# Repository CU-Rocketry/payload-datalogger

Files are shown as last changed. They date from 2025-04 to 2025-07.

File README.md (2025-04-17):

# payload-datalogger

Wirelessly configurable thermocouple data logging PCB implementing four MCP96RL00T on-board thermocouple to I2C converter ICs, an ESP32-C3 MCU, and flash storage.

## Screenshots

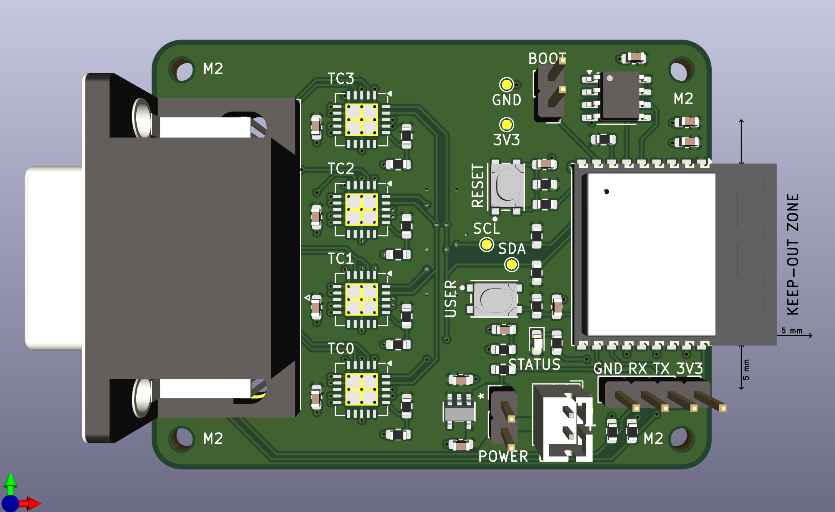
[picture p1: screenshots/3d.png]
3d

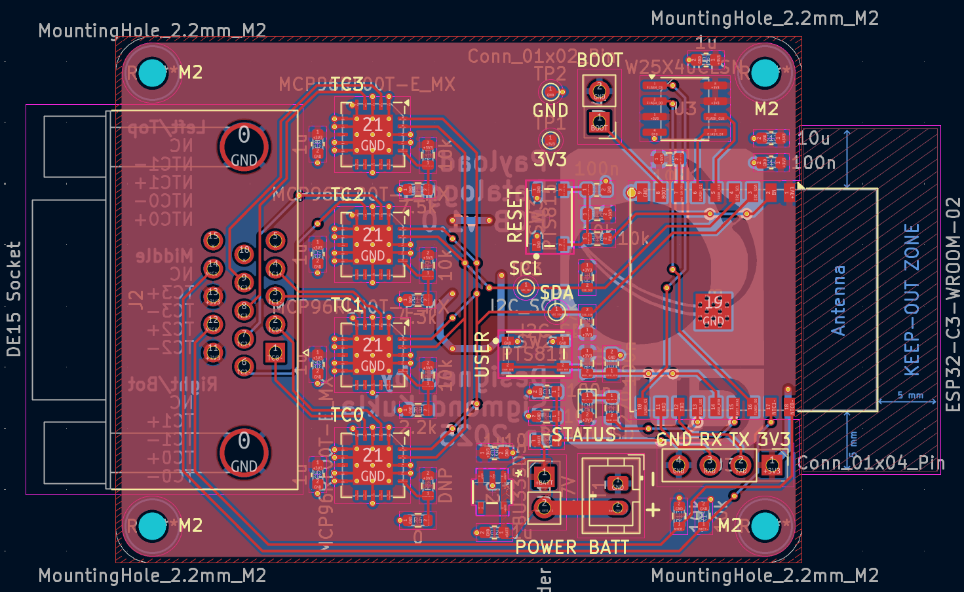
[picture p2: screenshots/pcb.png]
pcb

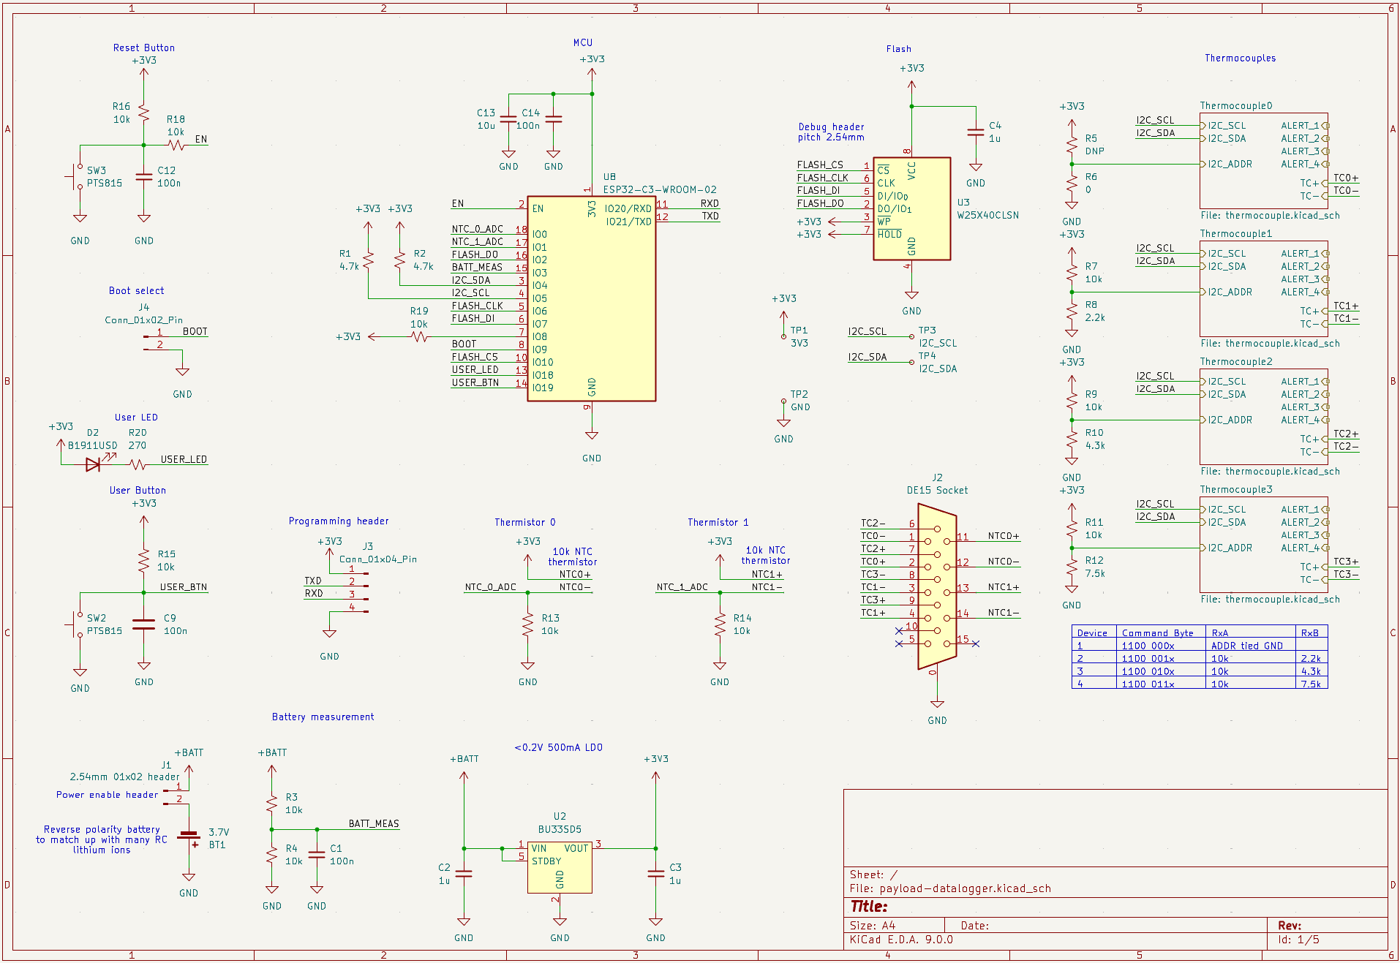
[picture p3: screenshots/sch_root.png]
schematic root

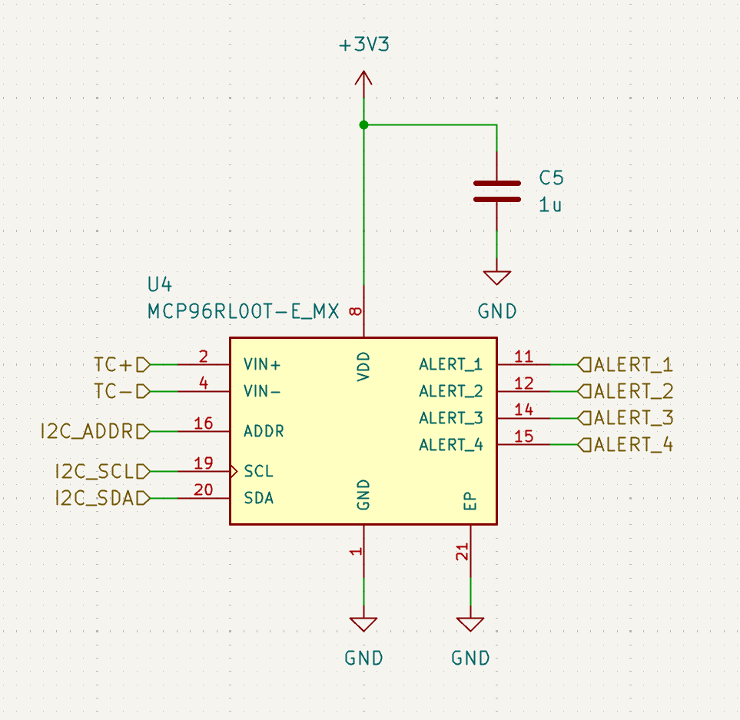
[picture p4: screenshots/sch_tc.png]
schematic thermocouple


## BOM

See [this spreadsheet].(https://docs.google.com/spreadsheets/d/12Mr7GmqM8tnob1ocJkmMWgOL1p1aouqN9iYZXRkocOg/edit?usp=sharing)

**BOM cost:** $65 (on DigiKey, for two boards with attrition)
Does not include cables.

Additionally, batteries should be purchased elsewhere such as the suggested Amazon links to remain economical.

## Firmware

Firmware source code is located in the `src/payload-datalogger` directory.
Source code, for ease of modification by all team members, relies on the Arduino hardware abstraction layer (HAL).
The PlatformIO IDE and toolchain is required to build and debug the firmware, meaning that the minimum prerequisites for payload datalogger firmware development are:
- [Visual Studio Code](https://code.visualstudio.com/download)
- [PlatformIO IDE extension](https://marketplace.visualstudio.com/items?itemName=platformio.platformio-ide)

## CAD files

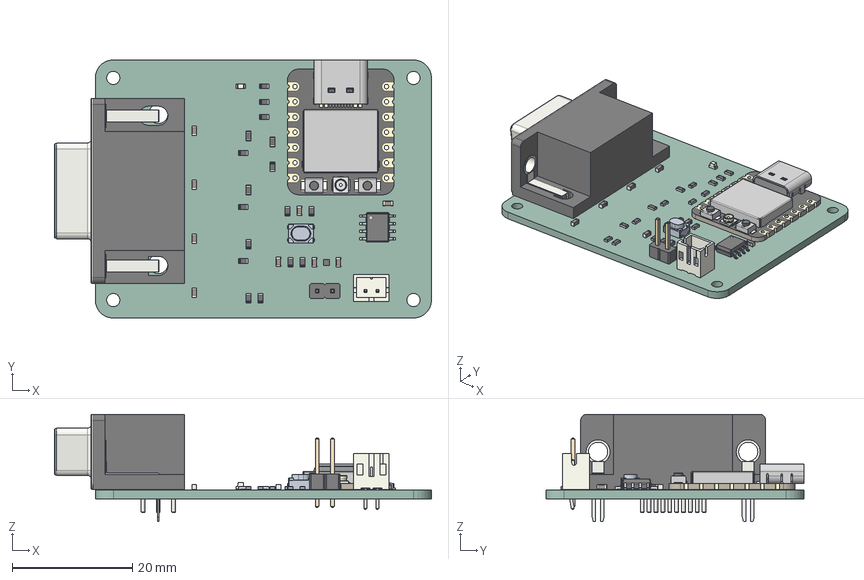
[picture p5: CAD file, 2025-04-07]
pcb/payload-datalogger.step
62.8 x 43.0 x 17.9 mm
C_0603_1608Metric x 9
JST_PH_B2B-PH-K_1x02_P2.00mm_Vertical
R_0603_1608Metric x 17
BOSS-EXTRUDE14_8_
BOSS-EXTRUDE7_4_
BOSS-EXTRUDE7_3_
BOSS-EXTRUDE14_4_
BOSS-EXTRUDE14_2_
BOSS-EXTRUDE14_11_
BOSS-EXTRUDE7_7_
BOSS-EXTRUDE14_9_
BOSS-EXTRUDE14_3_
BOSS-EXTRUDE14_7_
MIRROR2
BOSS-EXTRUDE14_5_
BOSS-EXTRUDE14_12_
BOSS-EXTRUDE7_8_
BOSS-EXTRUDE7_1_
BOSS-EXTRUDE14_10_
BOSS-EXTRUDE7_9_
BOSS-EXTRUDE14_6_
BOSS-EXTRUDE14_1_
BOSS-EXTRUDE7_6_
BOSS-EXTRUDE7_2_
CUT-EXTRUDE5
BOSS-EXTRUDE7_5_
U.FL Connector v1
Button (1) x 2
Shield
OnSemi_XDFN4-1EP_1.0x1.0mm_EP0.52x0.52mm
PinHeader_1x02_P2.54mm_Vertical
LED_0603_1608Metric
PTS815SJM250SMTRLFS_PART1
PTS815SJM250SMTRLFS_PART2
PTS815SJM250SMTRLFS_PART3
SOIC-8_3.9x4.9mm_P1.27mm
DSUB-15-HD_Socket_Horizontal_P2.29x2.54mm_EdgePinOffset8.35mm_Housed_ MountingHolesOffset10.89mm
payload-datalogger_PCB

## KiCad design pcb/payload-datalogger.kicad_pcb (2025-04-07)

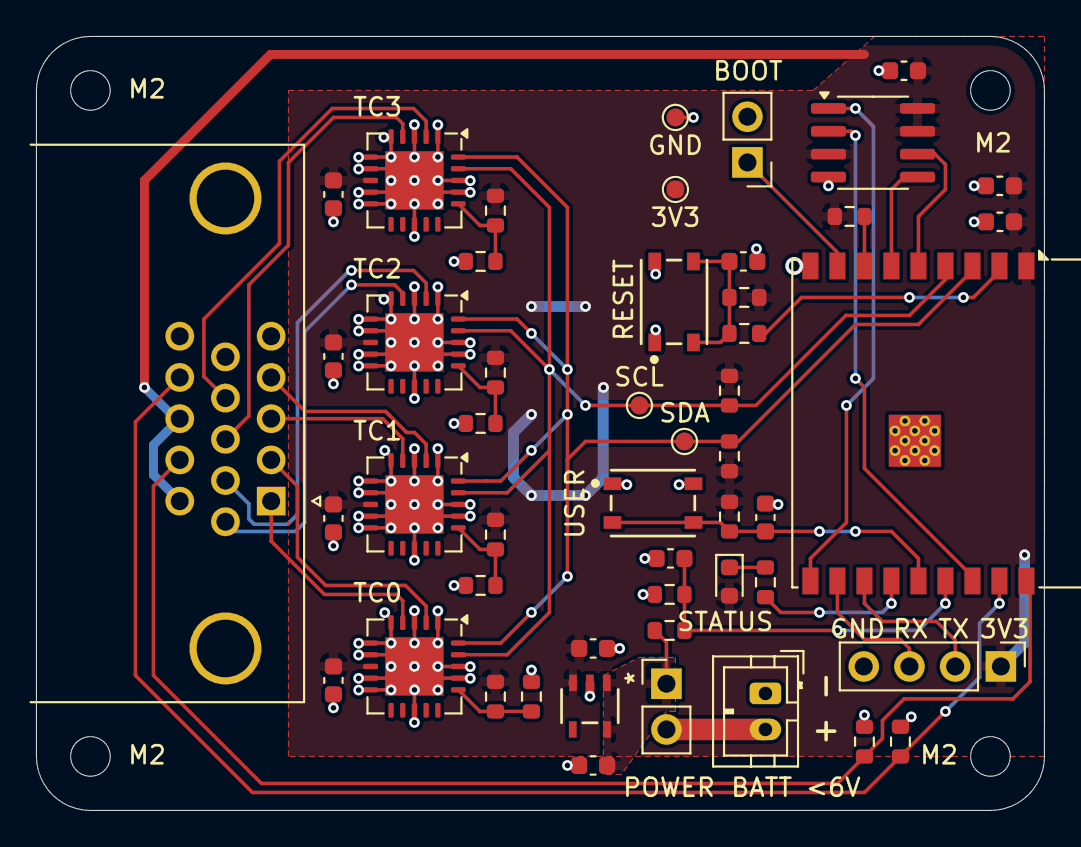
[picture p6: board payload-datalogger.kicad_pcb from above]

Board: 2 copper layers, 56.0 x 43.0 mm, 50 parts (0 on the bottom side), 34 nets.

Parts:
BT1: 3.7V; JST_PH_B2B-PH-K_1x02_P2.00mm_Vertical
C1, C9, C12, C14: 100n; C_0603_1608Metric
C2, C3, C4, C5, C6, C7, C8: 1u; C_0603_1608Metric
C13: 10u; C_0603_1608Metric
D2: B1911USD; LED_0603_1608Metric
J1: 2.54mm 01x02 header; PinHeader_1x02_P2.54mm_Vertical
J2: DE15 Socket; DSUB-15-HD_Socket_Horizontal_P2.29x2.54mm_EdgePinOffset8.35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
J3: Conn_01x04_Pin; PinHeader_1x04_P2.54mm_Vertical
J4: Conn_01x02_Pin; PinHeader_1x02_P2.54mm_Vertical
R1, R2: 4.7k; R_0603_1608Metric
R3, R4, R7, R9, R11, R13, R14, R15, R16, R18, R19: 10k; R_0603_1608Metric
R5: DNP; R_0603_1608Metric
R6: 0; R_0603_1608Metric
R8: 2.2k; R_0603_1608Metric
R10: 4.3k; R_0603_1608Metric
R12: 7.5k; R_0603_1608Metric
R20: 270; R_0603_1608Metric
SW2, SW3: PTS815; SW_Push_PTS815_SJM_250_SMTR_LFS
TP1: 3V3; TestPoint_Pad_D1.0mm
TP2: GND; TestPoint_Pad_D1.0mm
TP3: I2C_SCL; TestPoint_Pad_D1.0mm
TP4: I2C_SDA; TestPoint_Pad_D1.0mm
U2: BU33SD5; SSOP5_ROM
U3: W25X40CLSN; SOIC-8_3.9x4.9mm_P1.27mm
U4, U5, U6, U7: MCP96RL00T-E_MX; TQFN-20-1EP_5x5mm_P0.65mm_EP3.25x3.25mm
U8: ESP32-C3-WROOM-02

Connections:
+3V3: C3.1, C4.1, C5.1, C6.1, C7.1, C8.1, C13.1, C14.1, D2.2 (A), J2.11, J2.13, J3.1, R1.1, R2.1, R5.2, R7.2, R9.2, R11.2, R15.1, R16.2, R19.1, TP1.1, U2.3 (VOUT), U3.3 (~WP), U3.7 (~HOLD), U3.8 (VCC), U4.8 (VDD), U5.8 (VDD), U6.8 (VDD), U7.8 (VDD), U8.1 (3V3)
+BATT: C2.1, J1.1, R3.1, U2.1 (VIN), U2.5 (STDBY)
/BATT_MEAS: C1.1, R3.2, R4.1, U8.15 (IO3)
/BOOT: J4.1, U8.8 (IO9)
/EN: R18.2, U8.2 (EN)
/FLASH_CLK: U3.6 (CLK), U8.5 (IO6)
/FLASH_CS: U3.1 (~CS), U8.10 (IO10)
/FLASH_DI: U3.5 (DI/IO_{0}), U8.6 (IO7)
/FLASH_DO: U3.2 (DO/IO_{1}), U8.16 (IO2)
/I2C_SCL: R1.2, TP3.1, U4.19 (SCL), U5.19 (SCL), U6.19 (SCL), U7.19 (SCL), U8.4 (IO5)
/I2C_SDA: R2.2, TP4.1, U4.20 (SDA), U5.20 (SDA), U6.20 (SDA), U7.20 (SDA), U8.3 (IO4)
/NTC0-: J2.12, R13.1, U8.18 (IO0)
/NTC1-: J2.14, R14.1, U8.17 (IO1)
/RXD: J3.3, U8.11 (IO20/RXD)
/TC0+: J2.2, U4.2 (VIN+)
/TC0-: J2.1, U4.4 (VIN-)
/TC1+: J2.4, U5.2 (VIN+)
/TC1-: J2.3, U5.4 (VIN-)
/TC2+: J2.7, U6.2 (VIN+)
/TC2-: J2.6, U6.4 (VIN-)
/TC3+: J2.9, U7.2 (VIN+)
/TC3-: J2.8, U7.4 (VIN-)
/TXD: J3.2, U8.12 (IO21/TXD)
/Thermocouple0/I2C_ADDR: R5.1, R6.2, U4.16 (ADDR)
/Thermocouple1/I2C_ADDR: R7.1, R8.2, U5.16 (ADDR)
/Thermocouple2/I2C_ADDR: R9.1, R10.2, U6.16 (ADDR)
/Thermocouple3/I2C_ADDR: R11.1, R12.2, U7.16 (ADDR)
/USER_BTN: C9.1, R15.2, SW2.2, U8.14 (IO19)
/USER_LED: R20.2, U8.13 (IO18)
GND: BT1.1 (+), C1.2, C2.2, C3.2, C4.2, C5.2, C6.2, C7.2, C8.2, C9.2, C12.2, C13.2, C14.2, J2.0, J3.4, J4.2, R4.2, R6.1, R8.1, R10.1, R12.1, R13.2, R14.2, SW2.1, SW3.1, TP2.1, U2.2 (GND), U3.4 (GND), U4.1 (GND), U4.3 (GND), U4.5 (GND), U4.6 (GND), U4.7 (GND), U4.9 (GND), U4.10 (GND), U4.13 (GND), U4.17 (GND), U4.18 (GND), U4.21 (EP), U5.1 (GND), U5.3 (GND), U5.5 (GND), U5.6 (GND), U5.7 (GND), U5.9 (GND), U5.10 (GND), U5.13 (GND), U5.17 (GND), U5.18 (GND), U5.21 (EP), U6.1 (GND), U6.3 (GND), U6.5 (GND), U6.6 (GND), U6.7 (GND), U6.9 (GND), U6.10 (GND), U6.13 (GND), U6.17 (GND), U6.18 (GND), U6.21 (EP), U7.1 (GND), U7.3 (GND), U7.5 (GND), U7.6 (GND), U7.7 (GND), U7.9 (GND), U7.10 (GND), U7.13 (GND), U7.17 (GND), U7.18 (GND), U7.21 (EP), U8.9 (GND), U8.19 (GND)
unnamed: BT1.2 (-), J1.2
unnamed: C12.1, R16.1, R18.1, SW3.2
unnamed: D2.1 (K), R20.1
unnamed: R19.2, U8.7 (IO8)

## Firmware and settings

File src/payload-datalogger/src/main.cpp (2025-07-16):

#include <Arduino.h>
#include <WiFi.h>
#include <ESPAsyncWebServer.h>
#include <SPIFFS.h>
#include "peripherals.h"
#include "UserLED.h"
#include "UserButton.h"
#include <Thermistor.h>
#include <NTC_Thermistor.h>
#include "MCP9600.h"
#include <SPIMemory.h>
#include <cstdint>
#include <cstring>
#include <array>
#include <Preferences.h> // to store settings
#include <nvs_flash.h>

// ESP32 will create an AP with these credentials
const char *ssid = "CUR_Payload_Datalogger";
const char *password = "12345678";

IPAddress local_ip(192, 168, 1, 1); // static IP for ESP32
IPAddress gateway(192, 168, 1, 1);  // gateway is ESP32 itself
IPAddress subnet(255, 255, 255, 0); // subnet mask

AsyncWebServer server(80);

String renderLedToggleDiv();
String renderUserButtonDiv();
String renderRecordingToggleDiv();
String renderTimestepInputDiv();
String renderDownloadDiv();
String renderFlashDiv();
String renderTemperatureTable();
String renderIndex();

// Thermistors
#define NTC_REF_R 10000
#define NTC_NOMINAL_R 10000
#define NTC_NOMINAL_T 25
#define NTC_B 3435

NTC_Thermistor_ESP32 ntc0(NTC_0_PIN, NTC_REF_R, NTC_NOMINAL_R, NTC_NOMINAL_T, NTC_B, 3300, 4095);
NTC_Thermistor_ESP32 ntc1(NTC_1_PIN, NTC_REF_R, NTC_NOMINAL_R, NTC_NOMINAL_T, NTC_B, 3300, 4095);

#define TC0_ADDRESS 0x60
#define TC1_ADDRESS 0x61
#define TC2_ADDRESS 0x62
#define TC3_ADDRESS 0x63

TwoWire wire = TwoWire(0);

MCP9600 tc0(TC0_ADDRESS, &wire);
MCP9600 tc1(TC1_ADDRESS, &wire);
MCP9600 tc2(TC2_ADDRESS, &wire);
MCP9600 tc3(TC3_ADDRESS, &wire);

UserLED status_led(USER_LED_PIN);
UserButton user_btn(USER_BUTTON_PIN);

SPIFlash flash(FLASH_CS, &SPI);
uint32_t flash_capacity = 0;
uint32_t flash_pointer = 0; // should be aligned with page size
#define SECTOR_SIZE 4096 // 4kB sector size

bool led_state = false;
uint32_t last_led_time = 0;                // [ms] since boot
#define STATUS_LED_IDLE_DURATION 100       // [ms]
#define STATUS_LED_IDLE_DELAY 500          // [ms]
#define STATUS_LED_RECORDING_DURATION 1000 // [ms]
#define STATUS_LED_RECORDING_DELAY 1000    // [ms]

enum class LoggingState
{
    IDLE,
    RECORDING
};
LoggingState logging_state = LoggingState::IDLE;
uint32_t logging_interval = 1000; // [ms] between logging events, default to 1s
uint32_t last_logging_time = 0;   // [ms] since boot
uint32_t current_time = 0;        // [ms] since boot, fine for ~50 days
uint32_t start_time = 0;         // [ms] since boot, used to calculate timestamps
uint32_t timestamp = 0;         // [ms] since recording began
uint32_t iteration = 0;           // number of data points logged

#pragma pack(push, 1) // ensure no padding between struct members
struct DataPoint
{
    uint32_t iteration;
    uint32_t timestamp; // [ms] since boot
    float ntc0_temp;    // [C], assuming 32 bit float
    float ntc1_temp;    // [C]
    float tc0_temp;     // [C]
    float tc1_temp;     // [C]
    float tc2_temp;     // [C]
    float tc3_temp;     // [C]
};
#pragma pack(pop) // restore default packing
static_assert(sizeof(DataPoint) == 32, "DataPoint must be exactly 32 bytes");
#define POINTS_PER_PAGE (256 / sizeof(DataPoint)) // 8 data points per page
using Page = std::array<DataPoint, POINTS_PER_PAGE>;
using Buffer = std::array<std::uint8_t, sizeof(DataPoint) * POINTS_PER_PAGE>;
static_assert(Buffer{}.size() == 256, "Serialized page must be 256 bytes");

/*
We have 524,288 bytes of flash available (512kB).
This means that with each data point being 32 bytes, we may store 16,384 data points in total.
At a rate of 1 point per second, this gives us a total logging time of 4.5 hours.
If we log every 10 seconds, we can log for 45 hours.
*/

Page current_page; // Buffer for the current page of data points

Preferences preferences;

void flash_init();
void ap_init();
void webserver_init();
void thermocouples_init();
bool flushPageToFlash(const Page &page);
void flushPartialPage();
void loadMetadata();
void saveMetadata();
void dumpFlash();

void setup()
{
    Serial.begin(115200);
    // Serial.begin(921600);
    Serial.println("Serial started");


    // ONCE ONLY
    // Serial.println("Initializing NVS");
    // nvs_flash_erase();
    // nvs_flash_init();
    // preferences.begin("datalogger", false);
    // while(1);

    // thermocouples_init();
    flash_init();

    loadMetadata();

    dumpFlash(); // for debugging

    Serial.println("Flash dump complete");

    while (1){}

    status_led.init();
    user_btn.init();

    

    if (!SPIFFS.begin(true)) // for static file serving, true: format if mount fails
    {
        Serial.println("Error mounting SPIFFS");
        return;
    }
    Serial.println("SPIFFS mounted successfully");

    ap_init();
    webserver_init();

    Serial.println("Setup complete");
}

void loop()
{
    current_time = millis();
    timestamp = current_time - start_time;

    switch (logging_state)
    {
    case LoggingState::IDLE:
        // nothing needed here yet
        break;

    case LoggingState::RECORDING:
        // log data if timer elapsed
        if (current_time - last_logging_time >= logging_interval)
        { // if enough time has passed to log a new point

            // get all temperatures
            float ntc0_temp = ntc0.readCelsius();
            float ntc1_temp = ntc1.readCelsius();
            float tc0_temp = tc0.getHotJunctionTemp();
            float tc1_temp = tc1.getHotJunctionTemp();
            float tc2_temp = tc2.getHotJunctionTemp();
            float tc3_temp = tc3.getHotJunctionTemp();

            DataPoint data_point = {iteration, timestamp, ntc0_temp, ntc1_temp, tc0_temp, tc1_temp, tc2_temp, tc3_temp};

            current_page[iteration % POINTS_PER_PAGE] = data_point;

            last_logging_time = current_time; // reset timer
            iteration++;                      // increment iteration count

            if (iteration > 0 && iteration % POINTS_PER_PAGE == 0) // if we filled the page and are moving onto a new one
            {
                // write to flash
                if (flushPageToFlash(current_page))
                {
                    Serial.println("Successfully wrote page to flash");
                }
                else
                {
                    Serial.println("Failed to write page to flash.");
                }
            }
        }
        break;
    }

    // status LED blinking
    uint32_t led_delay;
    uint32_t led_duration;
    switch (logging_state)
    {
    case LoggingState::IDLE:
        led_delay = STATUS_LED_IDLE_DELAY;
        led_duration = STATUS_LED_IDLE_DURATION;
        break;

    case LoggingState::RECORDING:
        led_delay = STATUS_LED_RECORDING_DELAY;
        led_duration = STATUS_LED_RECORDING_DURATION;
        break;
    }
    if (led_state)
    {
        if (current_time - last_led_time >= led_duration)
        {
            status_led.set(false); // turn off LED
            led_state = false;
            last_led_time = current_time; // reset timer
        }
    }
    else
    {
        if (current_time - last_led_time >= led_delay)
        {
            status_led.set(true); // turn on LED
            led_state = true;
            last_led_time = current_time; // reset timer
        }
    }

    delay(10); // small delay to avoid busy loop
}

void flash_init()
{
    Serial.println("Flash init");
    SPI.begin(FLASH_CLK, FLASH_DO, FLASH_DI, FLASH_CS);

    flash.begin();
    // flash.setClock(1000000); // requires experimentation
    flash_capacity = flash.getCapacity();
    Serial.printf("Flash initialized. Capacity: %lu bytes\n", flash_capacity);
}

void ap_init()
{
    Serial.println("WiFi AP init");
    WiFi.softAP(ssid, password);
    WiFi.softAPConfig(local_ip, gateway, subnet);
    Serial.println("WiFi AP configured");
    Serial.print("SSID: ");
    Serial.println(ssid);
    Serial.print("Password: ");
    Serial.println(password);
    Serial.print("AP IP Address: ");
    Serial.println(WiFi.softAPIP());
}

void webserver_init()
{
    Serial.println("Web server init");

    server.serveStatic("/htmx.min.js", SPIFFS, "/htmx.min.js");
    server.serveStatic("/favicon.ico", SPIFFS, "/favicon.ico");
    server.serveStatic("/logo.png", SPIFFS, "/logo.png");

    server.on("/", HTTP_GET, [](AsyncWebServerRequest *request)
              { request->send(200, "text/html", renderIndex()); });

    server.on("/toggle_status_led", HTTP_POST, [](AsyncWebServerRequest *request)
              {
        led_state = !led_state;
        status_led.set(led_state);
        request->send(200, "text/html", renderLedToggleDiv()); });

    server.on("/user_button_state", HTTP_GET, [](AsyncWebServerRequest *request)
              { request->send(200, "text/html", renderUserButtonDiv()); });

    server.on("/toggle_recording", HTTP_POST, [](AsyncWebServerRequest *request)
              {
        if (logging_state == LoggingState::IDLE) {
            logging_state = LoggingState::RECORDING;
            Serial.println("Recording started.");
            last_logging_time = millis(); // Reset timer when starting
            start_time = millis(); // Reset start time for timestamp calculations
        } else if (logging_state == LoggingState::RECORDING) {
            logging_state = LoggingState::IDLE;
            flushPartialPage();
            Serial.println("Recording stopped.");
            // Optionally, write any remaining data in current_page if it's partially filled
            // This requires more complex logic to write a partial page or pad it. This could be a pain.
        }
        request->send(200, "text/html", renderRecordingToggleDiv()); });

    server.on("/set_rate", HTTP_POST, [](AsyncWebServerRequest *request)
              {
        if (request->hasParam("rate", true)) {
            int rate_val = request->getParam("rate", true)->value().toInt();
            if (rate_val > 0) {
                logging_interval = (uint32_t)rate_val;
                Serial.printf("Logging interval set to: %lu ms\n", logging_interval);
            } else {
                Serial.println("Invalid rate value received.");
            }
        }
        request->send(200, "text/html", renderTimestepInputDiv()); });

    server.on("/download_data", HTTP_GET, [](AsyncWebServerRequest *request)
              {
        Serial.println("Data download requested.");

        if (logging_state != LoggingState::IDLE) {
            request->send(400, "text/plain", "Stop logging before downloading.");
            return;
        }

        AsyncResponseStream *response = request->beginResponseStream("text/csv");
        response->addHeader("Content-Disposition", "attachment; filename=\"cur_payload_log.csv\"");
        response->print("Iteration,Timestamp,NTC0_Temp,NTC1_Temp,TC0_Temp,TC1_Temp,TC2_Temp,TC3_Temp\n");

        if (iteration == 0) {
            response->print("No data logged yet.\n");
            request->send(response);
            return;
        }
        
        Page data_page_buffer;
        uint32_t current_read_address = 0;
        uint32_t points_retrieved = 0;
        uint32_t total_points_to_read = iteration;

        Serial.printf("Preparing to download %lu data points. Flash pointer at %lu.\n", total_points_to_read, flash_pointer);

        while (current_read_address < flash_pointer && points_retrieved < total_points_to_read) {
            if (!flash.readAnything(current_read_address, data_page_buffer)) {
                Serial.printf("Flash read error at address %lu\n", current_read_address);
                break;
            }

            for (int i = 0; i < POINTS_PER_PAGE; ++i) {
                if (points_retrieved >= total_points_to_read) break;

                const DataPoint& dp = data_page_buffer[i];
                response->printf("%lu,%lu,%.3f,%.3f,%.3f,%.3f,%.3f,%.3f\n",
                                 dp.iteration, dp.timestamp, dp.ntc0_temp, dp.ntc1_temp,
                                 dp.tc0_temp, dp.tc1_temp, dp.tc2_temp, dp.tc3_temp);
                points_retrieved++;
            }
            current_read_address += sizeof(Page);
            
            delay(1); // yield in case of long downloads. maybe should yield longer even
        }
        
        Serial.printf("Sent %lu data points.\n", points_retrieved);
        request->send(response); });

    server.on("/flash_usage", HTTP_GET, [](AsyncWebServerRequest *request)
              { request->send(200, "text/html", renderFlashDiv()); });

    server.on("/refresh_table", HTTP_GET, [](AsyncWebServerRequest *request)
              { request->send(200, "text/html", renderTemperatureTable()); });

    server.on("/format_flash", HTTP_POST, [](AsyncWebServerRequest *request)
              {
        if (logging_state == LoggingState::RECORDING) {
            request->send(400, "text/plain", "Cannot format while recording.");
            return;
        }
        
        Serial.println("Formatting flash chip...");
        flash.eraseChip(); // Erase the flash
        
        // FIX: Reset local variables and persisted metadata in NVS
        flash_pointer = 0;
        iteration = 0;
        saveMetadata(); // Save the reset state
        
        Serial.println("Flash formatted successfully.");
        request->send(200, "text/html", renderFlashDiv()); });

    server.begin();
    Serial.println("Web server started");
}

void thermocouples_init()
{
    Serial.println("Thermocouples init");

    wire.begin(I2C_SDA, I2C_SCL, 85000);

    Serial.print("TC0 check: ");
    Serial.println(tc0.checkDeviceID() ? "OK" : "Failed");
    Serial.print("TC1 check: ");
    Serial.println(tc1.checkDeviceID() ? "OK" : "Failed");
    Serial.print("TC2 check: ");
    Serial.println(tc2.checkDeviceID() ? "OK" : "Failed");
    Serial.print("TC3 check: ");
    Serial.println(tc3.checkDeviceID() ? "OK" : "Failed");
}

inline void serializePage(const Page &page, Buffer &buffer)
{
    std::memcpy(buffer.data(), page.data(), buffer.size());
}

inline void deserializePage(const Buffer &buffer, Page &page)
{
    std::memcpy(page.data(), buffer.data(), buffer.size());
}

bool flushPageToFlash(const Page &page)
{
    // Check if flash is full
    if (flash_pointer + sizeof(Page) > flash_capacity) {
        Serial.println("Flash full! Write operation aborted.");
        logging_state = LoggingState::IDLE;
        return false;
    }

    // ensure that the NOR flash is erased to 0xFF before trying to write 0s in
    if (flash_pointer % SECTOR_SIZE == 0) { // if we are starting to write in a new sector
        Serial.printf("New sector address %lu. Erasing sector...\n", flash_pointer);
        if (!flash.eraseSector(flash_pointer)) {
            Serial.printf("Failed to erase sector. Logging stopped.\n");
            logging_state = LoggingState::IDLE;
            return false;
        }
        Serial.println("Sector erased successfully.");
    } 

    Serial.printf("Writing %d byte page to address %lu...\n", sizeof(page), flash_pointer);

    const uint8_t* data_ptr = reinterpret_cast<const uint8_t*>(&page); // treat page as a byte array

    for (size_t i = 0; i < sizeof(page); ++i) { // for each byte in the page
        flash.writeByte(flash_pointer + i, data_ptr[i]); // write to proper address
    }

    // Optional verification of written data
    /*
    Serial.println("Verifying written data...");
    Page read_back_page; // Create a temporary page object to read data into
    
    // Use readAnything, which seems to be more reliable.
    if (!flash.readAnything(flash_pointer, read_back_page)) {
         Serial.println("FATAL: Failed to read back data for verification.");
         return false;
    }

    // Compare the original data with the data read back from flash.
    if (memcmp(&page, &read_back_page, sizeof(page)) == 0) {
        Serial.println("Write verification successful.");
    } else {
        Serial.println("Write verification failed due to mismatch.");
        return false; 
    }
    */
    
    // Increment pointer and save metadata for persistence
    flash_pointer += sizeof(Page); // move flash pointer to next page
    saveMetadata(); // save current iteration and flash pointer to NVS    
    return true;
}

void flushPartialPage()
{
    uint32_t points_in_page = iteration % POINTS_PER_PAGE;
    if (points_in_page > 0)
    {
        printf("Flushing partial page with %lu points.\n", points_in_page);
        for (uint32_t i = points_in_page; i < POINTS_PER_PAGE; ++i)
        {
            current_page[i] = {}; // fill rest with zeros I guess
        }

        flushPageToFlash(current_page);
    }
}

void saveMetadata()
{
    preferences.begin("datalogger", false);
    preferences.putUInt("iter", iteration);
    preferences.putUInt("flash_ptr", flash_pointer);
    preferences.end();
    Serial.println("Metadata saved to non volatile storage.");
}

void loadMetadata()
{
    preferences.begin("datalogger", true);
    iteration = preferences.getUInt("iter", 0);
    flash_pointer = preferences.getUInt("flash_ptr", 0);
    preferences.end();
    Serial.printf("Metadata loaded: iteration=%lu, flash_pointer=%lu\n", iteration, flash_pointer);
}

// Dumps entire flash storage to Serial for debugging purposes
// this will be a long output. it should be entirely unformatted
// just writing each byte in hex format
void dumpFlash()
{
    // for (uint32_t addr = 0; addr < flash_capacity; addr += 16) {
    //     Serial.printf("%08X: ", addr);
    //     for (uint32_t i = 0; i < 16; ++i) {
    //         if (addr + i < flash_capacity) {
    //             Serial.printf("%02X ", flash.readByte(addr + i));
    //         } else {
    //             Serial.print("   ");
    //         }
    //     }
    //     Serial.println();
    // }

    Page data_page_buffer;
    uint32_t current_read_address = 0;
    uint32_t points_retrieved = 0;
    uint32_t total_points_to_read = iteration;

    Serial.printf("Preparing to download %lu data points. Flash pointer at %lu.\r\n", total_points_to_read, flash_pointer);

    Serial.printf("Iteration,Timestamp,NTC0_Temp,NTC1_Temp,TC0_Temp,TC1_Temp,TC2_Temp,TC3_Temp\r\n");

    while (current_read_address < flash_pointer && points_retrieved < total_points_to_read) {
        if (!flash.readAnything(current_read_address, data_page_buffer)) {
            Serial.printf("Flash read error at address %lu\n", current_read_address);
            break;
        }

        for (int i = 0; i < POINTS_PER_PAGE; ++i) {
            if (points_retrieved >= total_points_to_read) break;

            const DataPoint& dp = data_page_buffer[i];
            Serial.printf("%lu,%lu,%.3f,%.3f,%.3f,%.3f,%.3f,%.3f\r\n",
                                dp.iteration, dp.timestamp, dp.ntc0_temp, dp.ntc1_temp,
                                dp.tc0_temp, dp.tc1_temp, dp.tc2_temp, dp.tc3_temp);
            points_retrieved++;
        }
        current_read_address += sizeof(Page);
        
    }
    
    Serial.printf("Sent %lu data points.\r\n", points_retrieved);
}

String renderLedToggleDiv()
{
    String html = "<div id=\"led-toggle-div\">";
    html += "<label for=\"led-toggle\">Status LED:</label>";
    html += "<input type=\"checkbox\" id=\"led-toggle\" hx-post=\"/toggle_status_led\" hx-trigger=\"change\" hx-target=\"#led-toggle-div\" hx-swap=\"outerHTML\"";
    html += (led_state) ? " checked>" : ">";
    html += "<strong>";
    html += (led_state) ? "ON" : "OFF";
    html += "</strong></div>";
    return html;
}

String renderUserButtonDiv()
{
    String html = "<div id=\"user-button-div\">";
    html += "<button hx-get=\"/user_button_state\" hx-target=\"#user-button-div\" hx-swap=\"outerHTML\">Get User Button State</button>";
    bool button_is_pressed = user_btn.read();
    html += "<div>User Button State: <strong>";
    html += button_is_pressed ? "PRESSED" : "RELEASED";
    html += "</strong></div></div>";
    return html;
}

String renderRecordingToggleDiv()
{
    String html = "<div id=\"recording-toggle-div\">";
    html += "<div>Recording is currently <strong>";
    html += (logging_state == LoggingState::RECORDING) ? "ON" : "OFF";
    html += "</strong>.</div>";

    html += "<button hx-post=\"/toggle_recording\" hx-target=\"#recording-toggle-div\" hx-swap=\"outerHTML\" hx-trigger=\"click\">";
    html += (logging_state == LoggingState::RECORDING) ? "Stop Recording" : "Start Recording";
    html += "</button>";
    html += "</div>";
    return html;
}

String renderTimestepInputDiv()
{
    String html = "<div id=\"record-rate-div\">";
    html += "<div>Current recording interval: <strong>" + String(logging_interval) + "</strong> ms</div>";

    html += "<label for=\"record-rate\">Set recording interval:</label>";
    html += "<input type=\"number\" id=\"record-rate\" name=\"rate\" value=\"" + String(logging_interval) + "\" min=\"1\" hx-post=\"/set_rate\" hx-trigger=\"change\" hx-target=\"#record-rate-div\" hx-swap=\"outerHTML\">";
    html += " ms";
    html += "</div>";
    return html;
}

String renderDownloadDiv()
{
    String html = "<div id=\"download-data-div\">";
    html += "<div>Click the button below to download all logged temperature data in CSV format:</div>";
    // Using the <a> tag for downloads is better in my experience. The download attr gives a default filename.
    html += "<a href=\"/download_data\" download=\"datalog.csv\"><button type=\"button\">Download Data</button></a>";
    html += "</div>";
    return html;
}
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

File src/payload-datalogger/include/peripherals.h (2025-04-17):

#ifndef PERIPHERALS_H
#define PERIPHERALS_H

// ADC
#define NTC_0_PIN 0
#define NTC_1_PIN 1
#define BATT_MEAS_PIN 3

// SPI
#define FLASH_DO 2
#define FLASH_CLK 6
#define FLASH_DI 7
#define FLASH_CS 10

// I2C
#define I2C_SCL 5
#define I2C_SDA 4

// GPIO
#define USER_LED_PIN 18
#define USER_BUTTON_PIN 19

#endif

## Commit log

2025-04-01 Add PCB
    [payload-datalogger.kicad_pcb, payload-datalogger.kicad_sch, thermocouple.kicad_sch]
2025-04-01 Update kicad-library-sigmondkukla
2025-04-01 Connect flash decoupling cap to GND
    [payload-datalogger.kicad_pcb]
2025-04-01 Reroute battery measure
    [payload-datalogger.kicad_pcb]
2025-04-01 Tweak battery
    [payload-datalogger.kicad_pcb]
2025-04-01 Add rounded corners and 3.3V stitching
    [payload-datalogger.kicad_pcb]
2025-04-01 Update schematic for DE15
    [payload-datalogger.kicad_pcb, payload-datalogger.kicad_sch, thermocouple.kicad_sch]
2025-04-01 Update PCB to use d sub
    [payload-datalogger.kicad_pcb, payload-datalogger.kicad_sch]
2025-04-02 Add user button debounce to sch
    [payload-datalogger.kicad_pcb, payload-datalogger.kicad_sch]
2025-04-02 Add PCB button debounce
    [payload-datalogger.kicad_pcb, payload-datalogger.kicad_sch]
2025-04-03 Move D-sub further out
    [payload-datalogger.kicad_pcb, payload-datalogger.step]
2025-04-03 Increase thermal vias to 0.3mm hole
    [payload-datalogger.kicad_pcb, thermocouple.kicad_sch]
2025-04-03 Use larger Dsub for BOM optimization
    [payload-datalogger.kicad_pcb, payload-datalogger.kicad_sch]
2025-04-04 Prevent mounting hole overlap with dsub
    [payload-datalogger.kicad_pcb]
2025-04-04 Add ESP32-C3 3D model
    [payload-datalogger.kicad_pcb, payload-datalogger.step]
2025-04-07 Switch to ESP32 C3 WROOM module
    [payload-datalogger.kicad_pcb, payload-datalogger.kicad_sch]
2025-04-07 Increase ESP32 thermal pad via hole size
    [payload-datalogger.kicad_pcb]
2025-04-07 New bom
2025-04-07 Rearrange battery and LDO
    [payload-datalogger.kicad_pcb]
2025-04-07 Fix silkscreen overlap in DRC
    [payload-datalogger.kicad_pcb]
2025-04-07 Add BOM to readme
2025-04-07 Update production files
    [thermocouple.kicad_sch]
2025-04-07 Add USB to UART bridge to BOM on github
    [payload-datalogger.kicad_pcb]
2025-04-07 Fix TC2 routing and D-sub numbering
    [payload-datalogger.kicad_pcb]
2025-04-07 Fixed planes etc
    [payload-datalogger.kicad_pcb]
2025-04-07 Ordered PCB
    [payload-datalogger.kicad_pcb]
2025-04-17 Implement web and peripheral framework
2025-05-14 Move LED and button init out of constructor
2025-05-14 Add status LED blinking
2025-07-16 Update kicad library
